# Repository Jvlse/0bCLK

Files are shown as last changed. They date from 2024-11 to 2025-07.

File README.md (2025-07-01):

# 0bCLK
11 LED Binary Clock using an ATmega48A, [Datasheet](ATmega48A-PA-88A-PA-168A-PA-328-P-DS-DS40002061A.pdf)

Code is [here](https://github.com/Jvlse/0bCLK/blob/main/CLK/main.c)

## FEATURES:
 - Binary Time on 11 LED's with PWM brightnesscontrol
 - Control over buttons
 - Sleepmode with shown reduce of power
 - Timebase using Timer and quartz crystal (accuracy can be messured at PB0)
 - Flashing using ISP, for example using a USBasp and avrdude or an Arduino

## Schematic:
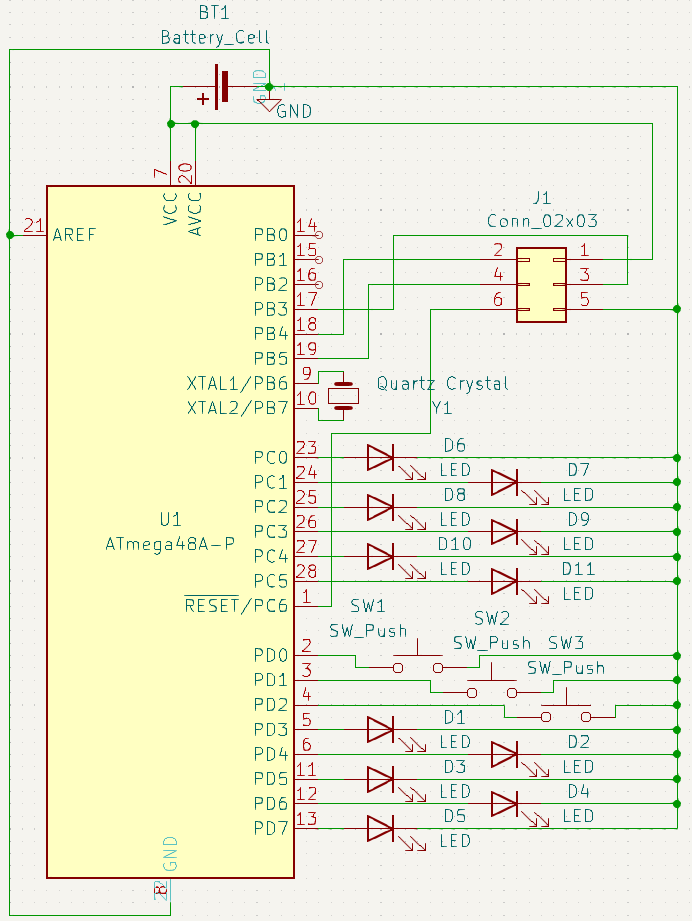
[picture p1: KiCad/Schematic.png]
Schematic


## PCB:
 - I used a mill for the 2-layer PCB
 - All components are mounted on the top and soldered on the bottom
 - I used CR2032 battery cells
 - For orientation of the ISP: 
   - the square pad on the footprint is the VCC pin of the 6-pin ISP

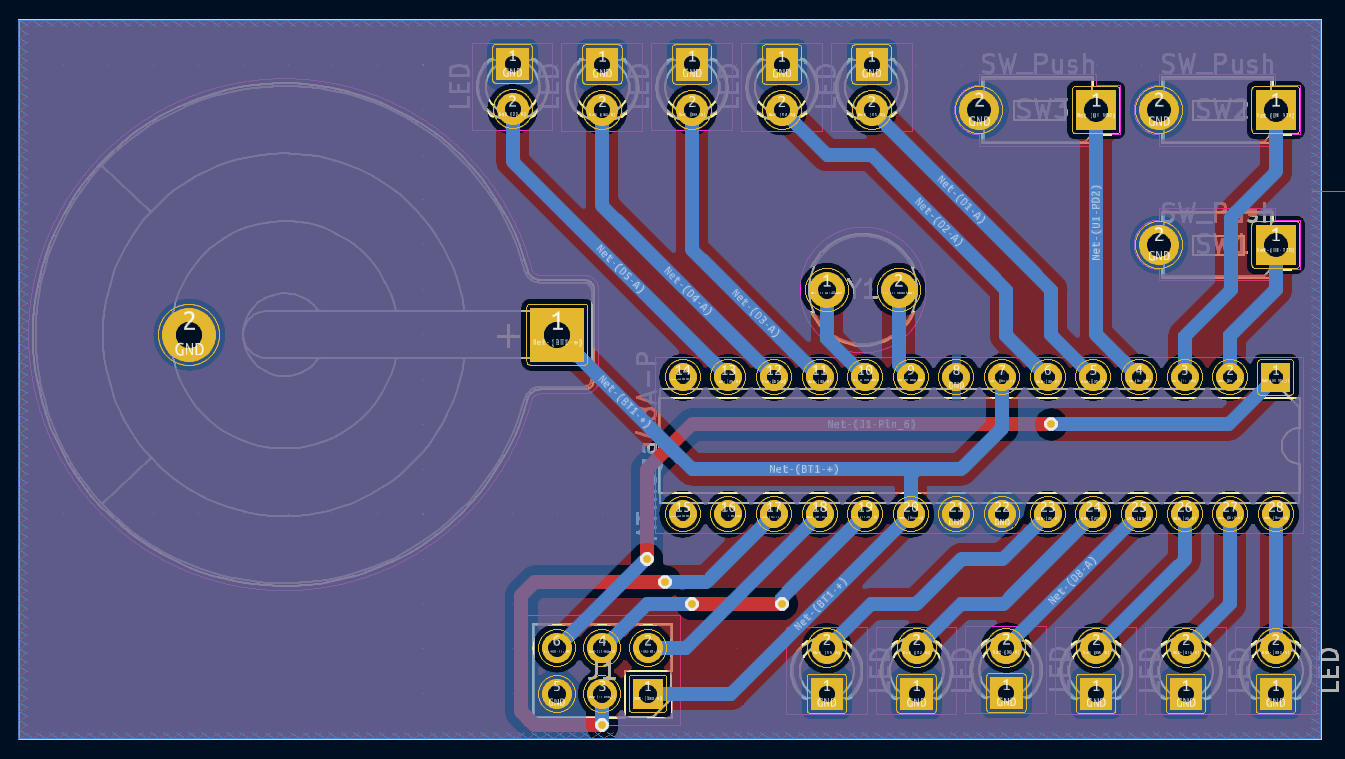
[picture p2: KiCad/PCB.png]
PCB


## Command for flashing using avrdude in Windows: 
```avrdude -c [programmer] -p m48A -Uflash:w:Path\To\CLK\Debug\CLK.hex:i```

Example using USBasp, path is "C:\Atmel_Studio\7.0\CLK\Debug\CLK.hex":

```avrdude -c usbasp -p m48A -Uflash:w:C:\Atmel_Studio\7.0\CLK\Debug\CLK.hex:i```

## Power saving:
 - If CPU is doing nothing (waiting for Timer interrupt) 
   - goes to PWR_SAVE (basically completely off exept async Timer and interrupt)
 - Disabling individual Timers, Two Wire Interface (TWI), Universal Synchronous Asynchronous Receiver Transmitter (USART0) and Analog Digital Converter (ADC)
 - more optimizations: turning off Watchdog timer, brown out, lower CPU CLK, lower voltage, using sleepmodes

## Fuse bits:
 - SPIEN: LEAVE ON!
   - else it won't be flashable using SPI/ISP anymore
 - WDTON: OFF 
   - Watchdog timer not needed
 - CKDIV8: OFF
   - no system clock division needed
 - BODLEVEL: Maybe 
   - if left off a brown out might lead to malfunction

## Power usage:
 - Default 6,5mA -> 35h runtime
 - PWR_SAVE 1,2µA -> 191666h ~ 20 years runtime

## CLK inaccuracy:
 - Reasons:
   - No Capacitors at quartz crystal, quartz temperature (25°C is optimal)
 - Messuring:
   - Output of Pulse Per Second (PPS) Signal at PB0 and meassuring using a counter

## Timers:
 - Timer 0: every ms for PWM
 - Timer 2: every second for timebase

## Buttons:
 - PD0 -> down (PCINT16/RXD)
 - PD1 -> up (PCINT17/TXD)
 - PD2 -> mode (PCINT18/INT0)

## Ports: 
 - Data Direction Register:
   - DDR=0: Pin is input (button)
   - DDR=1: Pin is output (LED)
 - PORT-Register: 
   - if DDR=0 
     - 1: Pull-up resistor is active, for button
     - 0: Pull-up not active
   - if DDR=1 
     - 1: High voltage output
     - 0: Low voltage output

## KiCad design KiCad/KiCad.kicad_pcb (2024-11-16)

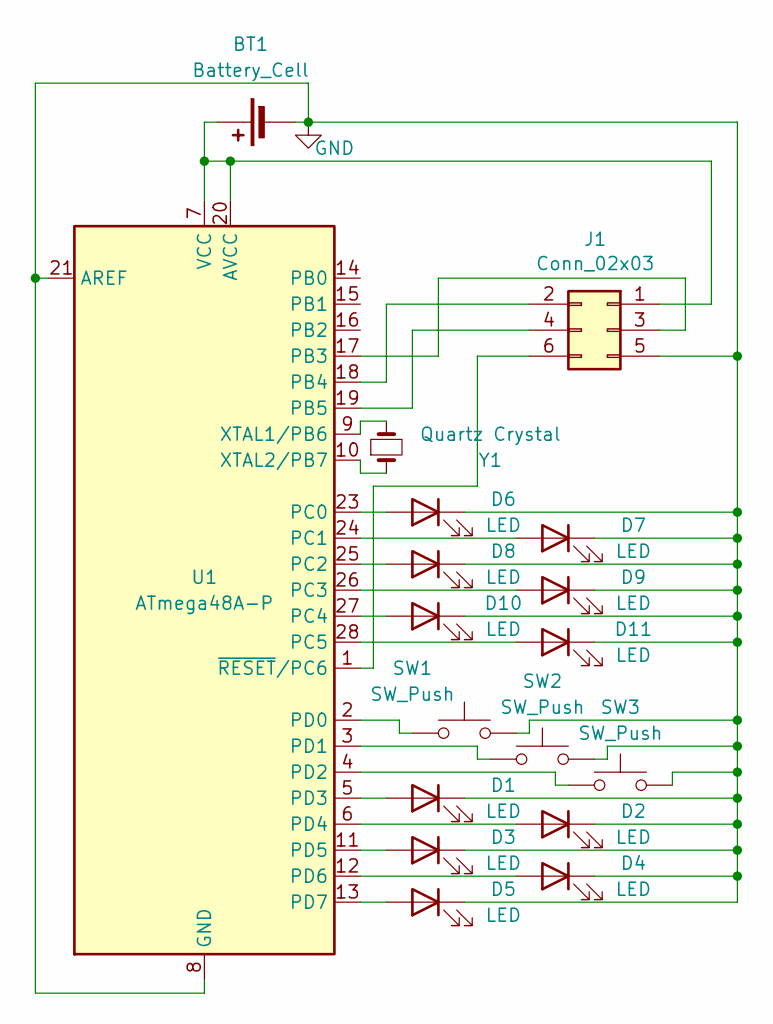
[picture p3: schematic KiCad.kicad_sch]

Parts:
BT1: Battery_Cell; BatteryHolder_Keystone_106_1x20mm
D1, D2, D3, D4, D5, D6, D7, D8, D9, D10, D11: LED; LED_D3.0mm
J1: Conn_02x03; PinSocket_2x03_P2.54mm_Vertical
SW1, SW2, SW3: SW_Push; SW_PUSH_1P1T_6x3.5mm_H5.0_APEM_MJTP1250
U1: ATmega48A-P; DIP-28_W7.62mm
Y1: Quartz Crystal; L_Radial_D6.0mm_P4.00mm

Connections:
GND: BT1.2 (-), D1.1 (K), D2.1 (K), D3.1 (K), D4.1 (K), D5.1 (K), D6.1 (K), D7.1 (K), D8.1 (K), D9.1 (K), D10.1 (K), D11.1 (K), J1.5, SW1.2, SW2.2, SW3.2, U1.8 (GND), U1.21 (AREF), U1.22 (GND)
unnamed: BT1.1 (+), J1.1, U1.7 (VCC), U1.20 (AVCC)
unnamed: D1.2 (A), U1.5 (PD3)
unnamed: D2.2 (A), U1.6 (PD4)
unnamed: D3.2 (A), U1.11 (PD5)
unnamed: D4.2 (A), U1.12 (PD6)
unnamed: D5.2 (A), U1.13 (PD7)
unnamed: D6.2 (A), U1.23 (PC0)
unnamed: D7.2 (A), U1.24 (PC1)
unnamed: D8.2 (A), U1.25 (PC2)
unnamed: D9.2 (A), U1.26 (PC3)
unnamed: D10.2 (A), U1.27 (PC4)
unnamed: D11.2 (A), U1.28 (PC5)
unnamed: J1.2, U1.18 (PB4)
unnamed: J1.3, U1.17 (PB3)
unnamed: J1.4, U1.19 (PB5)
unnamed: J1.6, U1.1 (~RESET/PC6)
unnamed: SW1.1, U1.2 (PD0)
unnamed: SW2.1, U1.3 (PD1)
unnamed: SW3.1, U1.4 (PD2)
unnamed: U1.9 (XTAL1/PB6), Y1.2
unnamed: U1.10 (XTAL2/PB7), Y1.1

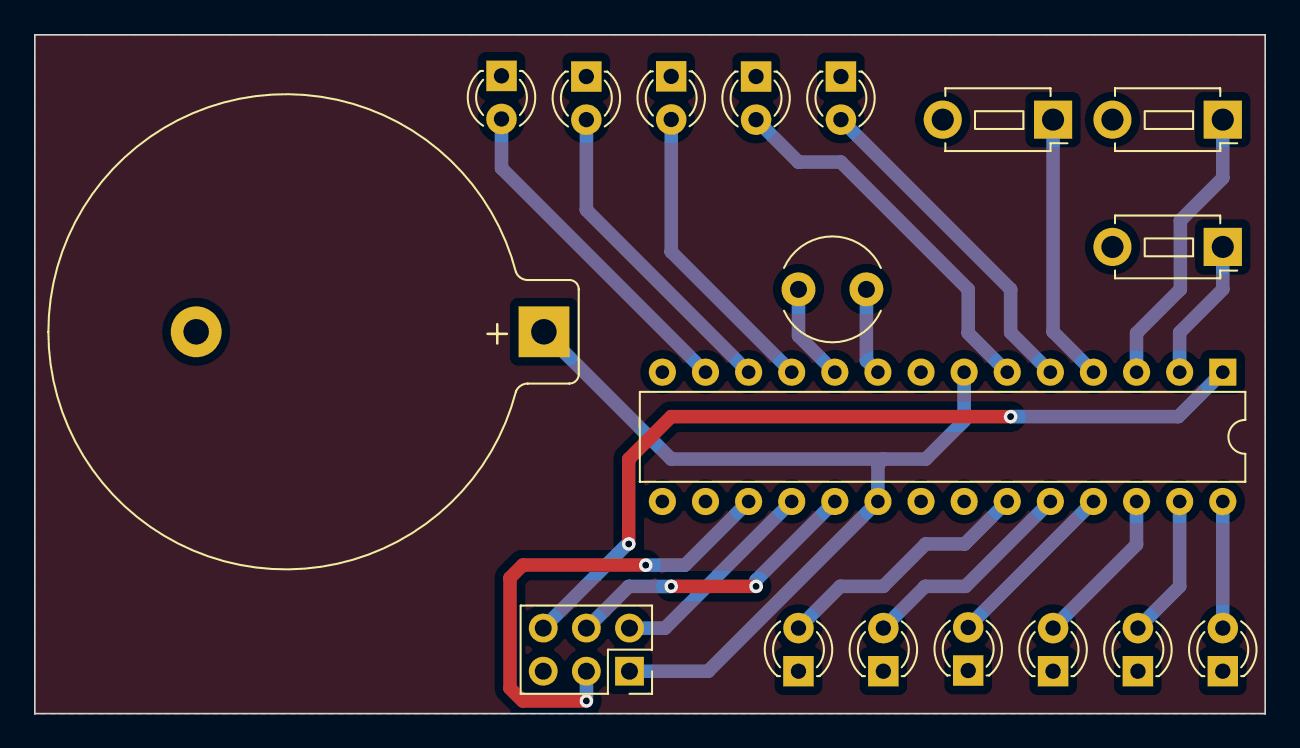
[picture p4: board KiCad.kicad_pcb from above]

Board: 2 copper layers, 72.5 x 40.0 mm, 18 parts (0 on the bottom side), 22 nets.

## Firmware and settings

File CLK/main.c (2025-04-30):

#define F_CPU 1000000UL
#include <avr/io.h>
#include <avr/interrupt.h>
#include <avr/sleep.h>
#include <avr/power.h>
#include <util/delay.h>

volatile uint8_t millisecond=0;
volatile uint8_t second=0;
 // example values for hour and minute
volatile uint8_t minute=30;
volatile uint8_t hour=7;
// if 0: Adjust brightness, 1: Adjust minutes, 2: Adjust hours
volatile uint8_t mode=0;
volatile uint8_t button=0;
// [0..3] LEDs off to brightest setting
volatile uint8_t pwm_mode=0;
volatile uint8_t tmp;
volatile uint8_t bounce=0;
// default is high because of the pull-up
volatile uint8_t portDtmp = 0b00000111;

void PWM(void);

int main(void) {
	// set bits 0..5 in DDR of the C ports to 1, these are outputs
	DDRC = (uint8_t) 0b00111111;
	// 0..2 are buttons, 3..7 are LEDs
	DDRD = (uint8_t) 0b11111000;
	// turn on pull-up resitors pins 0..3, these will be buttons 
	PORTD = (uint8_t) portDtmp;
	
	// set PCIE2 bit to 1 -> allows interrupt enable for PCINT16..23
	PCICR |= (1 << PCIE2);
	// enable interrupt for buttons, PCINT16..18
	PCMSK2 |= (1 << PCINT18) | (1 << PCINT17) | (1 << PCINT16);
	
	GTCCR |= (1 << TSM) | (1 << PSRASY);  // GTCCR -> General Timer/Counter Control Register
	// TSM -> Timer Synchronisation Mode: PSRASY bit will not be set to 0 by hardware
	// PSRASY -> prescaler reset for timer 2
	
	// timer 0 for pulse width modulation:
	TCCR0A |= (1 << WGM01); 	// CTC mode, turns on Clear Timer on Compare Match
	TCCR0B |= (1 << CS01);  	// Prescaler 8
	OCR0A = 125 - 1; 		// TCNT0=4, then end of counter -> 256*4/1000000 = 1024ms Intervall
	TIMSK0 |= (1 << OCIE0A);  	// Enable Compare Interrupt
	TIMSK0 |= (1 << TOIE0);   	// Timer0/Counter0 Interrupt Mask Register, TOIE0 -> Overflow Interrupt enable
	
	// setup asynchronous timer for Timer 2 (quartz crystal) -> keeps time in PWR_SAVE
	ASSR |= (1 << AS2);		// turn async mode on, Timer 2 -> quartz
	TCCR2A |= (1 << WGM21); 	// CTC Mode for Timer 2
	TCCR2B |= (1 << CS22) | (1 << CS21);	// set prescaler to 256
	OCR2A = 128 - 1;
	// Timer 2 frequency = TCCR2B*OCR2A/Quartz Frequency -> 256*128/32768 = 1s intervall
	TIMSK2 |= (1 << OCIE2A);	// enable Compare Interrupt
	TIMSK2 |= (1 << TOIE2);	// enable Overflow Interrupt
	
	// start timers
	GTCCR &= ~(1 << TSM);
	sei(); // enable global interrupts, set interrupt bit to 0 and I-Bit in SREG to 1
	
	// Power saving:
	sleep_enable();
	set_sleep_mode(SLEEP_MODE_PWR_SAVE);
	power_adc_disable();
	power_twi_disable();
	power_timer1_disable();
	power_usart0_disable();
	power_timer0_enable();
	
	sleep_mode(); // toggle sleep mode
	while(1) {
		if(pwm_mode == 0) {
			set_sleep_mode(SLEEP_MODE_PWR_SAVE);
			sleep_mode();
		}
	}
}

// Pulse Width Modulation calculation
void PWM() {
	if((millisecond < ((pwm_mode) * 5) - (4) || pwm_mode == 3) && pwm_mode != 0) { // turn on LEDs constantly at brightest mode
		sleep_disable();
		tmp = minute;
		tmp = (tmp & 0xF0) >> 4 | (tmp & 0x0F) << 4;
		tmp = (tmp & 0xCC) >> 2 | (tmp & 0x33) << 2;
		tmp = (tmp & 0xAA) >> 1 | (tmp & 0x55) << 1;
		// reverse minute byte, because port C is oriented the other way
		PORTC = (tmp >> 2);
		PORTD = (hour << 3) | 0b00000111;
	} else {
		sleep_disable();
		if(mode != 1) {
			PORTC = 0x00;
		}
		if(mode != 2) {
			PORTD = (0x00 << 3) | 0b00000111;
		}
		// set LEDs unused by mode to 0, for seeing which mode you're in
	}
}

// Interruptserviceroutine for PCINT16..18
ISR(PCINT2_vect) { 
	uint8_t changedbits;
	changedbits = PIND ^ portDtmp;
	portDtmp = PIND;
	
	// % 2 for pressing down and letting go
	bounce = (bounce + 1) % 2;  
	if(bounce == 0) {		
		if(changedbits & (1 << PD0)) // PCINT16 changed, down/- button
		{
			switch(mode) {
				case 0: // BRIGHTNESS
					pwm_mode = (pwm_mode - 1) % 4;
					break;
				
				case 1: // HOUR
					hour--;
					if(hour > 24) { // overflow (0xFF), because hour == -1
						hour = 23;
					}
					break;
				
				case 2: // MINUTE
					minute--;
					if(minute > 60) {
						minute = 59;
					}
					break;
			}
		}
		
		// PCINT17 changed, up/+ button
		if(changedbits & (1 << PD1)) 
		{
			switch(mode) {
				case 0: // BRIGHTNESS
					pwm_mode = (pwm_mode + 1) % 4;
					// at brightest pwm and timer 0 get disabled and PWR SAVE sleepmodi is used
					if(pwm_mode == 3) { 
						power_timer0_disable(); // or set_sleep_mode(SLEEP_MODE_PWR_SAVE);
					} else {
						power_timer0_enable(); // or set_sleep_mode(SLEEP_MODE_IDLE);
					}
					break;
				
				case 1: // HOUR
					hour++;
					if(hour == 24) {
						hour = 0;
					}
					break;
				
				case 2: // MINUTE
					minute++;
					if(minute == 60) {
						minute = 0;
					}
					break;
			}
		}

		// PCINT18 changed, mode button
		if(changedbits & (1 << PD2))
		{
			mode = (mode + 1) % 3;
		}
	}
}

// Will be called about ever millisecond
ISR(TIMER0_COMPA_vect) {	// at Timer0 compare,
	millisecond = (millisecond + 1) % 23; // 23 is for the pulse width
	PWM();
}

// Will be called every second
ISR(TIMER2_COMPA_vect) { 	// at Timer2 compare, generate timebase 
	second++;
	if(second >= 60) {
		second = 0;
		minute++;
		if(minute >= 60) {
			minute = 0;
			hour++;
			if(hour >= 24) {hour = 0;}
		}
	}
	
	PORTB = PORTB ^ 0b00000001; // output 0.5Hz at PB0 for measuring accuracy
	PWM();
}

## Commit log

2024-11-16 Added KiCad Project Schematic, PCB and images
    [KiCad.kicad_pcb, KiCad.kicad_sch]
2024-11-16 Changes to PCB
    [KiCad.kicad_pcb]
